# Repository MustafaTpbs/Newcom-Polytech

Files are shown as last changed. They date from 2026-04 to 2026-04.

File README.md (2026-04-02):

L’observatoire de Nançay a développé un banc de test pour les cartes dites NEWCOM afin de valider leur intégration dans les systèmes finaux. Il y a une soixantaine de cartes qui seront intégrées dans le Radiohéliographe de l’Observatoire Radioastronomique. 
	Le banc de test actuel fonctionne en envoyant des commandes à un générateur de signal qui est relié à un PCB d’interfaçage. L’opérateur branche la carte NEWCOM sur ce PCB d’interfaçage afin d’en observer les sorties sur un logiciel graphique installé sur son PC.
	La problématique : l’opérateur doit systématiquement manipuler un système de câbles volants afin de régler le banc de test sur ce qu’il veut observer. De plus, l’observation se fait sur un logiciel graphique qui affiche les signaux de sortie, donc l’opérateur doit obligatoirement avoir les compétences pour les analyser de lui-même. Cela est également très chronophage, car il doit le faire pour chaque signal, pour chaque carte.

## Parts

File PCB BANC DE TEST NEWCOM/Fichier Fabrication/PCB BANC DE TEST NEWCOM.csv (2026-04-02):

Id | Référence | Empreinte | Quantité | Désignation | FARNELL
1 | R5,R10,R15,R8,R13,R3,R12,R4 | R_0805_2012Metric | 8 | 5k | \
2 | H1,H4,H2,H3 | MountingHole_2.7mm_M2.5_DIN965_Pad | 4 | MountingHole_Pad | \
3 | R16,R14,R9,R1,R7,R2,R6,R11 | R_0805_2012Metric | 8 | 10k | \
4 | C4,C1 | C_1210_3225Metric_Pad1.33x2.70mm_HandSolder | 2 | 10u | 1759483
5 | C2,C3 | C_1206_3216Metric_Pad1.33x1.80mm_HandSolder | 2 | 100n | 3784278
6 | -5V,+12V,-12V,+5V | LED_0805_2012Metric_Pad1.15x1.40mm_HandSolder | 4 | LED | 3796308
7 | R25,R28 | R_0805_2012Metric | 2 | 500 | \
8 | R22,R23,R21,R24,R20,R19,R17,R29,R32,R18 | R_0805_2012Metric | 10 | 1k | \
9 | R31,R27 | R_0805_2012Metric | 2 | 9k1 | \
10 | J3,J1 | IDC-Header_2x08_P2.54mm_Vertical | 2 | Conn_02x08_Odd_Even | 1642020
11 | PNS | DSUB-25_Pins_Vertical_P2.77x2.84mm_MountingHoles | 1 | DB25_Pins | 1084687
12 | A1 | RaspberryPi_Pico_Common_Unspecified | 1 | RaspberryPi_Pico | 3996081 | (déjà acheté)
13 | R26,R30 | R_0805_2012Metric | 2 | 3k | \
14 | C5,C6 | C_1206_3216Metric_Pad1.33x1.80mm_HandSolder | 2 | 1u | 2991416
15 | IC1 | QFP50P1200X1200X160-64N | 1 | AD7606BSTZ | 4016556
16 | CARTE NEWCOM NS | DIN41612_B_2x32_Female_Vertical_THT | 1 | DIN41612_02x32_AB | 1096906
17 | J5 | TerminalBlock_Phoenix_MKDS-1,5-8-5.08_1x08_P5.08mm_Horizontal | 1 | Screw_Terminal_01x08 | 2008009

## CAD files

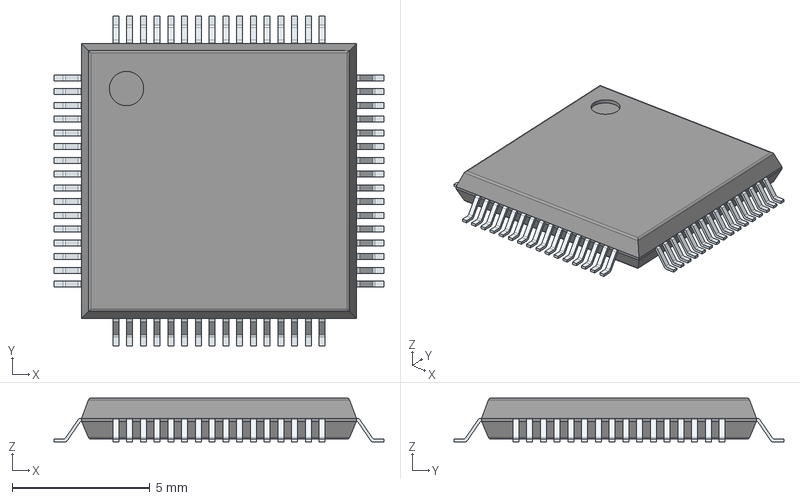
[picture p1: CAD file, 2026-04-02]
PCB BANC DE TEST NEWCOM/AD7606BSTZ/AD7606BSTZ/3D/AD7606BSTZ.stp
12.0 x 12.0 x 1.60 mm
PinsArrayLR
PinsArrayTB

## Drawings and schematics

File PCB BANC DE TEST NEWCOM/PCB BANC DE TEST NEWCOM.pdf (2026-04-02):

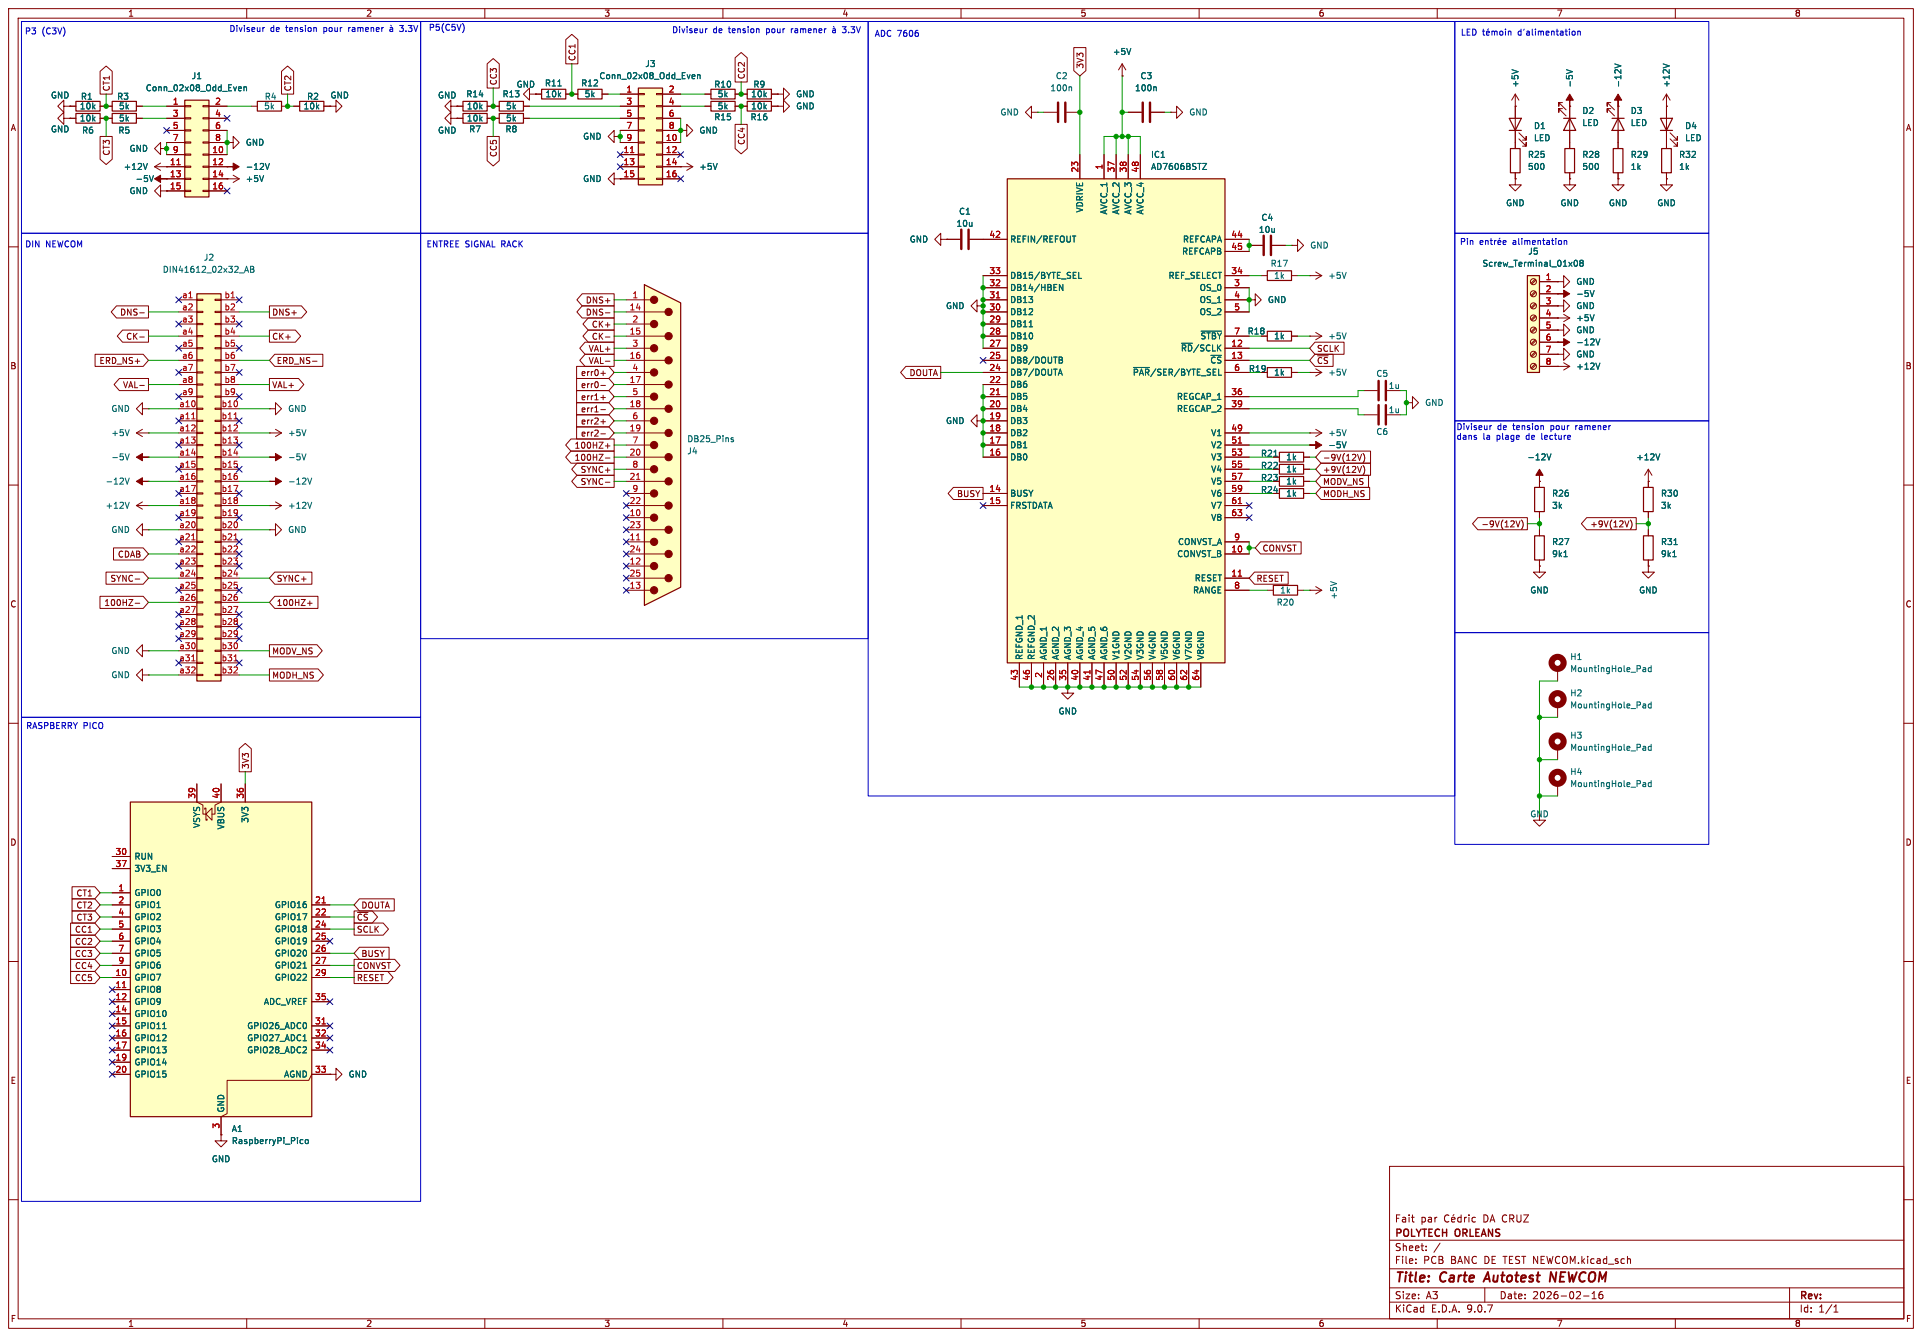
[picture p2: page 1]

Diviseur de tension pour ramener þÿà3.3V DIN NEWCOM

1 AGND_6 47 AVCC_2 37 V1GND 50 AVCC_3 38 V2GND 52 AVCC_4 48 V3GND 54 V4GND 56 V5GND 58 V6GND 60 V7GND 62 V8GND 64 REFCAPA 44 REFCAPB 45 REF_SELECT 34 OS_0 3 OS_1 4 OS_2 5 ~{STBY} 7 ~{RD}/SCLK 12 ~{CS}13 ~{PAR}/SER/BYTE_SEL 6 REGCAP_1 36 REGCAP_2 39 V1 49 V2 51 V3 53 V4 55 V5 57 V6 59 V7 61 V8 63 CONVST_A 9 CONVST_B 10 RESET 11 RANGE 8 GND

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

Fait par þÿCédric DA CRUZ

Id: 1/1 Title: Carte Autotest NEWCOM

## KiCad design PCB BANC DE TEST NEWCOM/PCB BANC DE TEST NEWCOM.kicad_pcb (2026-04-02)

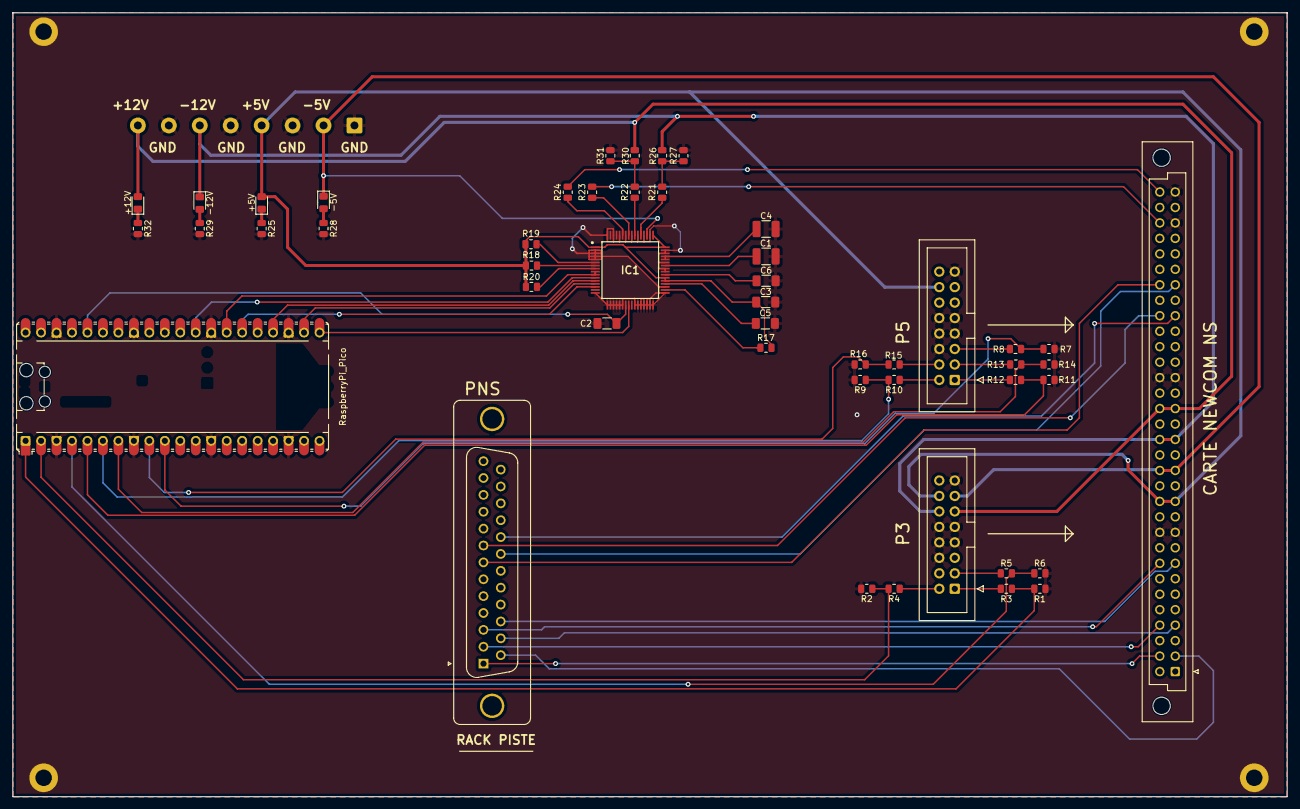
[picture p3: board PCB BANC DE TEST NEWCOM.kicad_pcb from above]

Board: 2 copper layers, 209.2 x 128.7 mm, 53 parts (1 on the bottom side), 58 nets.

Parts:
+5V, +12V: LED; LED_0805_2012Metric_Pad1.15x1.40mm_HandSolder
-5V, -12V: LED; LED_0805_2012Metric_Pad1.15x1.40mm_HandSolder
A1: RaspberryPi_Pico; RaspberryPi_Pico_Common_Unspecified
C1, C4: 10u; C_1210_3225Metric_Pad1.33x2.70mm_HandSolder
C2, C3: 100n; C_1206_3216Metric_Pad1.33x1.80mm_HandSolder
C5, C6: 1u; C_1206_3216Metric_Pad1.33x1.80mm_HandSolder
CARTE NEWCOM NS: DIN41612_02x32_AB; DIN41612_B_2x32_Female_Vertical_THT
H1, H2, H3, H4: MountingHole_Pad; MountingHole_2.7mm_M2.5_DIN965_Pad
IC1: AD7606BSTZ; QFP50P1200X1200X160-64N
J1, J3: Conn_02x08_Odd_Even; IDC-Header_2x08_P2.54mm_Vertical
J5: Screw_Terminal_01x08; TerminalBlock_Phoenix_MKDS-1,5-8-5.08_1x08_P5.08mm_Horizont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
PNS: DB25_Pins; DSUB-25_Pins_Vertical_P2.77x2.84mm_MountingHoles
R1, R2, R6, R7, R9, R11, R14, R16: 10k; R_0805_2012Metric
R3, R4, R5, R8, R10, R12, R13, R15: 5k; R_0805_2012Metric
R17, R18, R19, R20, R21, R22, R23, R24, R29, R32: 1k; R_0805_2012Metric
R25, R28: 500; R_0805_2012Metric
R26, R30: 3k; R_0805_2012Metric
R27, R31: 9k1; R_0805_2012Metric

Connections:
3V3: A1.36 (3V3), C2.2, IC1.23 (VDRIVE)
100HZ+: CARTE NEWCOM NS.b26, PNS.7
100HZ-: CARTE NEWCOM NS.a26, PNS.20
+5V: +5V.2 (A), C3.2, CARTE NEWCOM NS.a12, CARTE NEWCOM NS.b12, IC1.1 (AVCC_1), IC1.37 (AVCC_2), IC1.38 (AVCC_3), IC1.48 (AVCC_4), IC1.49 (V1), J1.14, J3.14, J5.4, R17.2, R18.2, R19.2, R20.1
+9V(12V): R22.2, R30.2, R31.1
+12V: +12V.2 (A), CARTE NEWCOM NS.a18, CARTE NEWCOM NS.b18, J1.11, J5.8, R30.1
-5V: -5V.1 (K), CARTE NEWCOM NS.a14, CARTE NEWCOM NS.b14, IC1.51 (V2), J1.13, J5.2
-9V(12V): R21.2, R26.2, R27.1
-12V: -12V.1 (K), CARTE NEWCOM NS.a16, CARTE NEWCOM NS.b16, J1.12, J5.6, R26.1
BUSY: A1.26 (GPIO20), IC1.14 (BUSY)
CC1: A1.5 (GPIO3), R11.1, R12.2
CC2: A1.6 (GPIO4), R9.1, R10.2
CC3: A1.7 (GPIO5), R13.2, R14.1
CC4: A1.9 (GPIO6), R15.2, R16.1
CC5: A1.10 (GPIO7), R7.1, R8.2
CK+: CARTE NEWCOM NS.b4, PNS.2
CK-: CARTE NEWCOM NS.a4, PNS.15
CONVST: A1.27 (GPIO21), IC1.9 (CONVST_A), IC1.10 (CONVST_B)
CT1: A1.1 (GPIO0), R1.1, R3.2
CT2: A1.2 (GPIO1), R2.1, R4.2
CT3: A1.4 (GPIO2), R5.2, R6.1
DNS+: CARTE NEWCOM NS.b2, PNS.1
DNS-: CARTE NEWCOM NS.a2, PNS.14
DOUTA: A1.21 (GPIO16), IC1.24 (DB7/DOUTA)
GND: A1.3 (GND), A1.8 (GND), A1.13 (GND), A1.18 (GND), A1.23 (GND), A1.28 (GND), A1.33 (AGND), A1.38 (GND), C1.1, C2.1, C3.1, C4.2, C5.2, C6.2, CARTE NEWCOM NS.a10, CARTE NEWCOM NS.a20, CARTE NEWCOM NS.a30, CARTE NEWCOM NS.a32, CARTE NEWCOM NS.b10, CARTE NEWCOM NS.b20, H1.1, H2.1, H3.1, H4.1, IC1.2 (AGND_1), IC1.3 (OS_0), IC1.4 (OS_1), IC1.5 (OS_2), IC1.16 (DB0), IC1.17 (DB1), IC1.18 (DB2), IC1.19 (DB3), IC1.20 (DB4), IC1.21 (DB5), IC1.22 (DB6), IC1.26 (AGND_2), IC1.27 (DB9), IC1.28 (DB10), IC1.29 (DB11), IC1.30 (DB12), IC1.31 (DB13), IC1.32 (DB14/HBEN), IC1.33 (DB15/BYTE_SEL), IC1.35 (AGND_3), IC1.40 (AGND_4), IC1.41 (AGND_5), IC1.43 (REFGND_1), IC1.46 (REFGND_2), IC1.47 (AGND_6), IC1.50 (V1GND), IC1.52 (V2GND), IC1.54 (V3GND), IC1.56 (V4GND), IC1.58 (V5GND), IC1.60 (V6GND), IC1.62 (V7GND), IC1.64 (V8GND), J1.6, J1.7, J1.8, J1.9, J1.10, J1.15, J3.6, J3.7, J3.8, J3.9, J3.10, J3.15, J5.1, J5.3, J5.5, J5.7, R1.2, R2.2, R6.2, R7.2, R9.2, R11.2, R14.2, R16.2, R25.2, R27.2, R28.2, R29.2, R31.2, R32.2
MODH_NS: CARTE NEWCOM NS.b32, R24.2
MODV_NS: CARTE NEWCOM NS.b30, R23.2
unnamed: +5V.1 (K), R25.1
unnamed: -5V.2 (A), R28.1
unnamed: -12V.2 (A), R29.1
unnamed: +12V.1 (K), R32.1
unnamed: IC1.8 (RANGE), R20.2
unnamed: C4.1, IC1.44 (REFCAPA), IC1.45 (REFCAPB)
unnamed: C1.2, IC1.42 (REFIN/REFOUT)
unnamed: IC1.34 (REF_SELECT), R17.1
unnamed: C5.1, IC1.36 (REGCAP_1)
unnamed: C6.1, IC1.39 (REGCAP_2)
unnamed: IC1.53 (V3), R21.1
unnamed: IC1.55 (V4), R22.1
unnamed: IC1.57 (V5), R23.1
unnamed: IC1.59 (V6), R24.1
unnamed: IC1.6 (~PAR/SER/BYTE_SEL), R19.1
unnamed: IC1.7 (~STBY), R18.1
unnamed: J1.1, R3.1
unnamed: J1.2, R4.1
unnamed: J1.3, R5.1
unnamed: J3.1, R12.1
unnamed: J3.2, R10.1
unnamed: J3.3, R13.1
unnamed: J3.4, R15.1
unnamed: J3.5, R8.1
RESET: A1.29 (GPIO22), IC1.11 (RESET)
SCLK: A1.24 (GPIO18), IC1.12 (~RD/SCLK)
SYNC+: CARTE NEWCOM NS.b24, PNS.8
SYNC-: CARTE NEWCOM NS.a24, PNS.21
VAL+: CARTE NEWCOM NS.b8, PNS.3
VAL-: CARTE NEWCOM NS.a8, PNS.16
~CS: A1.22 (GPIO17), IC1.13 (~CS)

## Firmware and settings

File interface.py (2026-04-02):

##################################################################################################
##################################################################################################
##################################################################################################
#Cette interface est prévue pour fonctionner en étant situer dans votre répertoire de test Hardpy#
##################################################################################################
##################################################################################################
##################################################################################################
#Bien se placer dans le répertoire de test Harpy pour que les chemins soient corrects

import sys
import os
import json
import glob
import subprocess
import shutil
from pathlib import Path
from datetime import datetime
from PySide6.QtWidgets import (QApplication, QWidget, QVBoxLayout, QHBoxLayout, 
                             QPushButton, QLineEdit, QLabel, QStackedWidget, QMessageBox)
from PySide6.QtCore import Qt, QUrl, QTimer
from PySide6.QtWebEngineWidgets import QWebEngineView
from inventree.api import InvenTreeAPI


class InterfaceHardPy(QWidget):
    def __init__(self):
        super().__init__()
        
        # --- Configuration InvenTree ---
        self.SERVER_ADDRESS = 'http://192.168.2.1'#Mettre l'adresse de votre serveur inventree
        self.MY_USERNAME = 'cedri' #Mettez votre identifiant
        self.MY_PASSWORD = 'Sedan2003!' #Mettez votre mot de passe
        self.cwd = Path.cwd() #Bien se placer dans le répertoire de test Harpy pour que les chemins soient corrects
        
        # Utilisation de chemins POSIX pour Linux (/reports)
        self.reports_wd = self.cwd / "reports"
        
        # Création du dossier reports s'il n'existe pas
        os.makedirs(self.reports_wd, exist_ok=True)
        
        self.product_id = ""
        self.api = None
        
        # 1. Vérification de la connexion avant de charger l'interface
        if not self.init_inventree():
            sys.exit(1)

        self.initUI()

    def init_inventree(self):
        """Initialise la connexion à l'API InvenTree au démarrage."""
        try:
            self.api = InvenTreeAPI(self.SERVER_ADDRESS, username=self.MY_USERNAME, password=self.MY_PASSWORD)
            print("Connecté à InvenTree")
            return True
        except Exception as e:
            QMessageBox.critical(
                None, 
                "Erreur Fatale - InvenTree Inaccessible",
                f"Impossible de se connecter au serveur : {self.SERVER_ADDRESS}\n\n"
                f"Erreur : {str(e)}\n\n"
                "L'interface va se fermer. Vérifiez que les containers Docker sont lancés."
            )
            return False

    def initUI(self):
        self.setWindowTitle("HardPy Operator Panel (Linux)")
        self.resize(1200, 900)
        self.setStyleSheet("background-color: #E0E0E0;") 

        self.stacked_widget = QStackedWidget(self)
        main_layout = QVBoxLayout(self)
        main_layout.setContentsMargins(0, 0, 0, 0)
        main_layout.addWidget(self.stacked_widget)

        self.creer_page_accueil()
        self.creer_page_test()
        self.creer_page_fin()

    def creer_page_accueil(self):
        page = QWidget()
        layout = QVBoxLayout(page)
        
        self.input_id = QLineEdit()
        self.input_id.setPlaceholderText("Entrez l'ID du Stock Item InvenTree...")
        self.input_id.setStyleSheet("color: black; padding: 15px; font-size: 16px; border-radius: 8px; border: 1px solid #CCC;")
        self.input_id.setFixedWidth(400)

        btn_valider = QPushButton("DÉMARRER LE TEST")
        btn_valider.setStyleSheet("""
            QPushButton { background-color: #0078D7; color: white; padding: 15px; font-weight: bold; border-radius: 8px; }
            QPushButton:hover { background-color: #005A9E; }
        """)
        btn_valider.setFixedWidth(250)
        btn_valider.clicked.connect(self.lancer_test)

        layout.addStretch()
        layout.addWidget(self.input_id, alignment=Qt.AlignCenter)
        layout.addSpacing(20)
        layout.addWidget(btn_valider, alignment=Qt.AlignCenter)
        layout.addStretch()
        self.stacked_widget.addWidget(page)

    def creer_page_test(self):
        page = QWidget()
        layout = QVBoxLayout(page)
        layout.setContentsMargins(0, 0, 0, 0)

        header = QHBoxLayout()
        header.setContentsMargins(10, 5, 10, 5)
        
        btn_refresh = QPushButton("🔄 Actualiser")
        btn_refresh.setFixedWidth(120)
        btn_refresh.clicked.connect(lambda: self.navigateur.reload())
        
        self.label_id_test = QLabel("ID Stock: ---")
        self.label_id_test.setStyleSheet("font-weight: bold; font-size: 14px; color: black;")

        header.addWidget(btn_refresh)
        header.addStretch()
        header.addWidget(self.label_id_test)
        layout.addLayout(header)

        self.navigateur = QWebEngineView()
        layout.addWidget(self.navigateur, stretch=1) 

        btn_fin = QPushButton("VALIDER FIN DE TEST ET ENVOYER RÉSULTATS")
        btn_fin.setStyleSheet("background-color: #D83B01; color: white; padding: 20px; font-weight: bold; font-size: 16px;")
        btn_fin.clicked.connect(self.terminer_test)
        layout.addWidget(btn_fin)

        self.stacked_widget.addWidget(page)

    def creer_page_fin(self):
        page = QWidget()
        layout = QVBoxLayout(page)
        self.label_id_fin = QLabel("Test Terminé")
        self.label_id_fin.setStyleSheet("font-size: 24px; font-weight: bold; color: black;")
        self.label_id_fin.setAlignment(Qt.AlignCenter)
        
        btn_restart = QPushButton("RETOUR À L'ACCUEIL")
        btn_restart.setFixedWidth(200)
        btn_restart.clicked.connect(lambda: self.stacked_widget.setCurrentIndex(0))
        
        layout.addStretch()
        layout.addWidget(self.label_id_fin)
        layout.addSpacing(20)
        layout.addWidget(btn_restart, alignment=Qt.AlignCenter)
        layout.addStretch()
        self.stacked_widget.addWidget(page)

    def lancer_test(self):
        if not self.input_id.text().strip():
            QMessageBox.critical(self, "Erreur", "L'identifiant du Stock Item est requis.")
            return
        
        self.product_id = self.input_id.text().strip()
        self.label_id_test.setText(f"Stock Item ID : {self.product_id}")

        # Lancement de HardPy avec détection de terminal Linux
        try:
            # On copie l'environnement actuel
            env = os.environ.copy()
            # On supprime les variables qui font crasher le snap gnome-terminal
            env.pop('LD_LIBRARY_PATH', None)
            env.pop('GTK_PATH', None)

            commande = f'gnome-terminal -- bash -c "hardpy run Harpy; exec bash"'
            # On passe le nouvel environnement "propre"
            subprocess.Popen(commande, cwd=self.cwd, shell=True, env=env)
            
        except Exception as e:
            print(f"Erreur lancement terminal : {e}")

        self.stacked_widget.setCurrentIndex(1)
        # On attend que le serveur HardPy démarre
        QTimer.singleShot(3000, lambda: self.navigateur.setUrl(QUrl("http://localhost:8000/")))

    def terminer_test(self):
        """Génère les JSON spécifiques, les envoie à InvenTree, puis nettoie."""
        
        liste_fichiers = glob.glob(os.path.join(str(self.reports_wd), "*.json"))
        fichiers_bruts = [f for f in liste_fichiers if not os.path.basename(f).startswith(self.product_id + "_")]
        
        if not fichiers_bruts:
            QMessageBox.warning(self, "Erreur", "Aucun fichier JSON de résultat brut trouvé.")
            return
        
        chemin_json_brut = max(fichiers_bruts, key=os.path.getctime)
        horodatage = datetime.now().strftime("%Y%m%d_%H%M%S")
        
        try:
            with open(chemin_json_brut, 'r', encoding='utf-8') as f:
                data = json.load(f)
                
            # 1. TRAITEMENT GLOBAL
            statut_global_texte = data.get("status", "failed")
            is_global_success = (statut_global_texte == "passed")
            
            nom_fichier_global = f"{self.product_id}_global_{horodatage}.json"
            chemin_fichier_global = os.path.join(str(self.reports_wd), nom_fichier_global)
            
            with open(chemin_fichier_global, 'w', encoding='utf-8') as f_out:
                json.dump(data, f_out, indent=4)

            with open(chemin_fichier_global, 'rb') as f_attach:
                self.api.post(
                    'stock/test/',
                    data={
                        'stock_item': self.product_id,
                        'test': 'Validity',
                        'result': is_global_success,
                        'notes': f"Résultat global : {statut_global_texte.upper()}"
                    },
                    files={'attachment': f_attach}
                )

            # 2. TRAITEMENT MODULES
            modules_data = data.get("modules", {})
            for module_key, module_info in modules_data.items():
                nom_module = module_info.get("name", module_key)
                statut_module = module_info.get("status", "failed")
                is_module_success = (statut_module == "passed")
                
                nom_fichier_module = f"{self.product_id}_{module_key}_{horodatage}.json"
                chemin_fichier_module = os.path.join(str(self.reports_wd), nom_fichier_module)
                
                with open(chemin_fichier_module, 'w', encoding='utf-8') as f_mod_out:
                    json.dump(module_info, f_mod_out, indent=4)
                
                with open(chemin_fichier_module, 'rb') as f_mod_attach:
                    self.api.post(
                        'stock/test/',
                        data={
                            'stock_item': self.product_id,
                            'test': nom_module, 
                            'result': is_module_success,
                            'notes': f"Sous-module : {module_key} - Statut : {statut_module.upper()}"
                        },
                        files={'attachment': f_mod_attach}
                    )
                
                try:
                    os.remove(chemin_fichier_module)
                except Exception as e:
                    print(f"Avertissement: Impossible de supprimer {chemin_fichier_module} : {e}")

            try:
                os.remove(chemin_json_brut)
            except Exception as e:
                print(f"Avertissement: Impossible de supprimer le fichier brut original : {e}")

            self.label_id_fin.setText(f"Résultats envoyés avec succès pour l'ID {self.product_id}")
            self.stacked_widget.setCurrentIndex(2)
            
        except Exception as e:
            QMessageBox.critical(self, "Erreur Transmission", f"Échec de l'envoi à InvenTree : {str(e)}")

if __name__ == '__main__':
    app = QApplication(sys.argv)
    window = InterfaceHardPy()
    window.show()
    sys.exit(app.exec())

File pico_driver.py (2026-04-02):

import picod

class PicoDevice:
    def __init__(self, port='/dev/ttyACM0'):
        # Initialisation de la connexion picod
        self.p = picod.pico(device=port)

        PIN_SOURCE = 8
        self.p.gpio_open(PIN_SOURCE)
        self.p.gpio_set_output(PIN_SOURCE, 1)

        # Définition des pins d'entrée de la pico - TEST RF
        self.gp_ct1 = 0 # Pin 1 physique (CT1)
        self.gp_ct2 = 1 # Pin 2 physique (CT2)
        self.gp_ct3 = 2 # Pin 4 physique (CT3)
        self.gp_cc1 = 3 # Pin 5 physique (CC1)
        self.gp_cc2 = 4 # Pin 6 physique (CC2)
        self.gp_cc3 = 5 # Pin 7 physique (CC3)
        self.gp_cc4 = 6 # Pin 9 physique (CC4)
        self.gp_cc5 = 7 # Pin 10 physique (CC5)

        # Définition des pins de sortie de la pico - TEST MODULATION
        self.adc_out = 16

        if not self.p.connected:
            raise ConnectionError(f"Pico non détectée sur {port}")

        # Ouverture et configuration des GPIO
        self.p.gpio_open(self.gp_cc1)
        self.p.gpio_open(self.gp_cc2)
        self.p.gpio_open(self.gp_cc3)
        self.p.gpio_open(self.gp_cc4)
        self.p.gpio_open(self.gp_cc5)
        self.p.gpio_open(self.gp_ct1)
        self.p.gpio_open(self.gp_ct2)
        self.p.gpio_open(self.gp_ct3)

        self.p.gpio_open(self.adc_out)
        
        # Configuration en entrée des pins
        self.p.gpio_set_input(self.gp_cc1)
        self.p.gpio_set_input(self.gp_cc2)
        self.p.gpio_set_input(self.gp_cc3)
        self.p.gpio_set_input(self.gp_cc4)
        self.p.gpio_set_input(self.gp_cc5)
        self.p.gpio_set_input(self.gp_ct1)
        self.p.gpio_set_input(self.gp_ct2)
        self.p.gpio_set_input(self.gp_ct3)

        self.p.gpio_set_input(self.adc_out)
        
    def read_status_rf_cc1(self):
        res1, level_cc1 = self.p.gpio_read(self.gp_cc1)
            
        if res1 == 0 :
            return (level_cc1 == 1)
        
    def read_status_rf_cc2(self):
        res1, level_cc2 = self.p.gpio_read(self.gp_cc2)
            
        if res1 == 0 :
            return (level_cc2 == 1)
        
    def read_status_rf_cc3(self):
        res1, level_cc3 = self.p.gpio_read(self.gp_cc3)
            
        if res1 == 0 :
            return (level_cc3 == 1)
        
    def read_status_rf_cc4(self):
        res1, level_cc4 = self.p.gpio_read(self.gp_cc4)
            
        if res1 == 0 :
            return (level_cc4 == 1)
        
    def read_status_rf_cc5(self):
        res1, level_cc5 = self.p.gpio_read(self.gp_cc5)
            
        if res1 == 0 :
            return (level_cc5 == 1)
        
    def read_status_rf_ct1(self):
        res1, level_ct1 = self.p.gpio_read(self.gp_ct1)
            
        if res1 == 0 :
            return (level_ct1 == 1)
        
    def read_status_rf_ct2(self):
        res1, level_ct2 = self.p.gpio_read(self.gp_ct2)
            
        if res1 == 0 :
            return (level_ct2 == 1)
        
    def read_status_rf_ct3(self):
        res1, level_ct3 = self.p.gpio_read(self.gp_ct3)
            
        if res1 == 0 :
            return (level_ct3 == 1)

    def read_status_modulation(self): #à faire
        return False
    
    def read_retard(self): #impossible
        return False
    
    def read_voltage_5V(self):
        return False #à faire
    
    def read_voltage_minus5V(self):
        return False #à faire
    
    def read_voltage_12V(self):
        return False #à faire
    
    def read_voltage_minus12V(self):
        return False #à faire

    def close(self):
        self.p.close()

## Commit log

2026-04-02 Deleting history
    [AD7606BSTZ.stp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]
2026-04-02 correction erreurs de lancement
    [interface.py]
2026-04-02 Version 1.0, prêt pour la présentation
